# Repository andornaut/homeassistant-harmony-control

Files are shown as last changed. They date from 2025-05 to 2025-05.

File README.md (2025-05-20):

# homeassistant-harmony-remote

* [v1](./v1/)

Physical remote control for Home Assistant

Inspiration: [The Everything Remote](https://www.thestockpot.net/videos/theeverythingremote)

* [Overview (video)](https://www.youtube.com/watch?v=Pe_ozZkrRAw)
* [Build instructions (video)](https://www.youtube.com/watch?v=JU_7mb1ue7o&t=2059s)
* [3D models (.3mf and .step)](https://www.printables.com/model/1281626-everything-remote-esp32-powered-universal-remote)
* [Order PCB from PCBWay](https://www.pcbway.com/project/shareproject/The_Everything_Remote_The_Stock_Pot_ff1fe6b5.html)

## Bill of materials (BOM)

Item | Quantity | Description
--- | --- | ---
[Lithium Ion Battery - 1500mAh](https://www.sparkfun.com/lithium-ion-battery-1500mah-iec62133-certified.html) | 1 | 3.7V at 1500 mAh
[Mill-Max 315-43-116-41-001000](https://www.digikey.ca/en/products/detail/mill-max-manufacturing-corp/315-43-116-41-001000/4455239) | 2 | [315 series](https://mm.digikey.com/Volume0/opasdata/d220001/medias/docus/2481/310%2C%20311%2C%20315%20Series%20%28in.%29.pdf) "very low profile" 16-pin socket
[Mill-max 3320-0-00-15-00-00-03-0](https://www.digikey.ca/en/products/detail/mill-max-manufacturing-corp/3320-0-00-15-00-00-03-0/4147392) | 32 | Pins to connec the microcontroller to the sockets
[Panasonic ERJ-3EKF1002V](https://www.digikey.ca/en/products/detail/panasonic-electronic-components/ERJ-3EKF1002V/196066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) | 2 | 10 kΩ pull-up resistors
[SCHURTER tactile switches](https://www.digikey.ca/en/products/detail/schurter-inc/1301-9315-24/2643953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) | 24 | 6x6x0.5mm, 0.5A 12v
[SparkFun Thing Plus - ESP32 WROOM (USB-C)](https://www.sparkfun.com/sparkfun-thing-plus-esp32-wroom-usb-c.html) | 1 | Microcontroller

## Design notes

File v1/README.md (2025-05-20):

# Version 1 of the Homeassistant Harmony Remote

|col1 | col2 | col3|
|--- | --- | ---|
|Mute||Power|
|Vol↓||Vol↑|
||Up||
|Left|Select|Right|
||Down||
|Back||Home|

|col1| col2|
|--- | ---|
|Cameras|CBC|
|Crave|Netflix|
|Switch|VLC|
|Xbox|YouTube|

| GPIO Pin | Button ID | Wake Supported | External Pullup Resistor Required |
|---|---|:---:|:---:|
| GPIO4 | power | Yes | |
| GPIO12 | home | Yes | |
| GPIO13 | mute | Yes | |
| GPIO14 | shortcut_1 | Yes | |
| GPIO16 | shortcut_2 | | |
| GPIO17 | shortcut_3 | | |
| GPIO18 | shortcut_4 | | |
| GPIO19 | shortcut_5 | | |
| GPIO21 | shortcut_6 | | |
| GPIO22 | shortcut_7 | | |
| GPIO23 | shortcut_8 | | |
| GPIO25 | volume_up | Yes | |
| GPIO26 | volume_down | Yes | |
| GPIO27 | select_button | Yes | |
| GPIO32 | back | Yes | |
| GPIO33 | left | Yes | |
| GPIO34 | right | Yes | Yes |
| GPIO36 | up | Yes | Yes |
| GPIO39 | down | Yes | Yes |

## Software

* [Setting up ESPHome for Home Assistant (video)](https://www.youtube.com/watch?v=7PoUWszwaFk)

1. Navigate to [https://web.esphome.io/](https://web.esphome.io/) using Google Chrome
1. Connect the remote via USB
1. Click "Connect" and select the remote device
1. Click "Prepare for first use"
   * Press and hold the "Boot" button on the microcontroller to enter programming mode
1. Click "Connect to wi-fi"
1. Navigate to [ESPHome Device Builder](https://esphome.io/guides/getting_started_command_line#esphome-device-builder-docker)

Run Google Chrome as root to avoid permission problems when attempting to access the USB port:

```bash
sudo google-chrome --no-sandbox --no-first-run --no-default-browser-check &
```

## Hardware

### Bill of materials (BOM)

Category | Quantity | Part
--- | --- | ---
Microcontroller | 1 | [SparkFun Thing Plus - ESP32 WROOM (USB-C)](https://www.sparkfun.com/sparkfun-thing-plus-esp32-wroom-usb-c.html) ([pin out](https://cdn.sparkfun.com/assets/3/9/5/f/e/SparkFun_Thing_Plus_ESP32_WROOM_C_graphical_datasheet2.pdf))
Screws | 4 | M3x8mm screws
Sockets (16-pin)| 2 | [Mill-Max 315-43-116-41-001000](https://www.digikey.ca/en/products/detail/mill-max-manufacturing-corp/315-43-116-41-001000/4455239)
Socket pins | 32 | [Mill-Max 3320-0-00-15-00-00-03-0](https://www.digikey.ca/en/products/detail/mill-max-manufacturing-corp/3320-0-00-15-00-00-03-0/4147392)
Threaded inserts | 4 | [M3x3mm (short) threaded inserts](https://cnckitchen.store/products/gewindeeinsatz-threaded-insert-m3-short-100-stk-pcs)

### Set ESP32 flash voltage to 3.3v to use GPIO12 for a button

* [esptool GitHub](https://github.com/espressif/esptool)
* [espefuse.py documentation](https://docs.espressif.com/projects/esptool/en/latest/esp32/espefuse/index.html)

In order to use GPIO12 for a button, we must ensure the ESP32 always uses 3.3V for flash voltage.

**Warning:** This is permanent! Only do this if you are sure your board uses 3.3V flash like the SparkFun ESP32 Thing Plus.

```bash
sudo apt install python3 python3-pip
python3 -m venv .venv
source .venv/bin/activate
pip3 install esptool

# Plug in your SparkFun ESP32 Thing Plus (USB-C) and find your its serial port
ls /dev/ttyUSB* /dev/ttyACM* 2>/dev/null

# Read the initial state
espefuse.py --port /dev/ttyUSB1 summary

# Set the flash voltage to 3.3V
espefuse.py --port /dev/ttyUSB1 set_flash_voltage 3.3V

# Verify the new state: look for a line like:
# VDD_SDIO: 3.3V (set by eFuse)
espefuse.py --port /dev/ttyUSB1 summary
```

## Developing

* [Overall process](../README.md#developing)

### [Ergogen](https://github.com/ergogen/ergogen)

* [Project folder](./ergogen)
* [Configuration file](./ergogen/config.yaml)

Ergogen preview

1. Convert the prototype to Ergogen's DSL, and then save it to [`./ergogen/config.yaml`](./ergogen/config.yaml)
   * If prototyping using this [online version of Ergogen](https://ergogen.cache.works/), then download the "raw.txt" file
1. Run `npm run build` to generate and save outlines and pcbs to `../dist/v1/ergogen/`
    * Alternatively, run `npm run watch` or `npm run watch-and-copy-pcbs-to-kicad`

### [KiCad](https://www.kicad.org/)

* [Project folder](./kicad)

KiCad preview

1. Run `npm run copy-pcbs-to-kicad` to copy the `../dist/v1/ergogen/pcbs/*.kicad_pcb` files generated by Ergogen to [`./kicad/`](./kicad/)
1. Run `xdg-open ./v2/kicad/left.kicad_pcb`
1. Route the PCBs in [`./kicad/`](./kicad/), and then save them to [`./kicad/routed/`](./kicad/routed/)
    * If you've generated new PCB files using Ergogen, then you can run `npm run copy-traces-from-routed` to copy traces from the PCBs in [`./kicad/routed/`](./kicad/routed/) back to those of the same name in [`./kicad/`](./kicad/)
1. Run `npm run copy-pcbs-to-routed && npm run fab-jlcpcb` to generate and save gerber and drill files to `../dist/v1/kicad/jlcpcb/*.zip`
1. Submit the `../dist/v1/kicad/jlcpcb/*.zip` files to [JLCPCB](https://jlcpcb.com/)

### [OnShape](https://cad.onshape.com)

* [Project folder](./onshape)

OnShape preview

1. Create a new document
1. Start a new sketch
1. Select "Import DXF or DWG files" > "Import ..." (at the bottom of the dialog) > Select `../dist/v2/ergogen/outlines/full.dxf`
1. Design a keyboard case
1. Export `*.step` files to [`./onshape/`](./onshape/)

### [OrcaSlicer](https://github.com/SoftFever/OrcaSlicer)

1. Open or create an OrcaSlicer project file
1. Import `*.step` files from [`./onshape/`](./onshape/)
1. Print the keyboard case

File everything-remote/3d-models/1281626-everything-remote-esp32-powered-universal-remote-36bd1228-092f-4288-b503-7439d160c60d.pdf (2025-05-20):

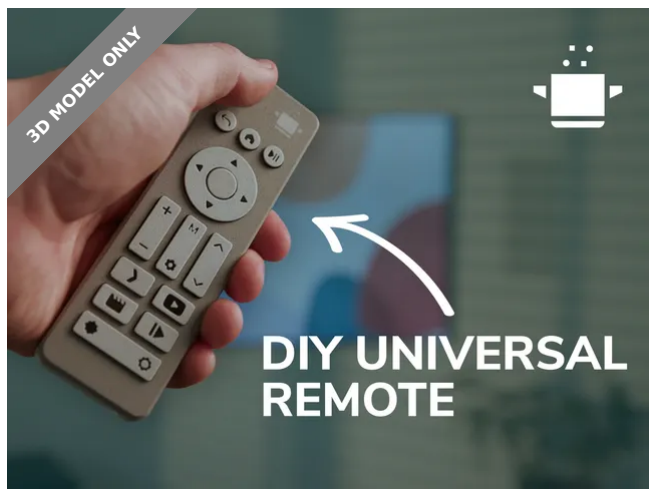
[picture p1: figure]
3D MODEL ONLY

## Summary

ESPHome-powered universal remote for Home Assistant. 3D printable case, labeled/blank buttons + full guide.

Gadgets (https://printables.com/model?categoryId=21) > Portable Devices (https://printables.com/model?categoryId=28)

Tags: | esp32 | smarthome | thestockpot

UPDATED 8/5 - Replaced Shell_Bottom and Shell_Top with fixed versions

Build your own universal smart remote!

This project turns a simple ESP32 and tactile buttons into a powerful, battery-powered remote for Home Assistant — perfect for media control, lights, scenes and more.

You can 3D print this enclosure, solder up the simple electronics, and load my ESPHome config to get started right away. No coding skills required! Check out the resources below for everything you need to make your own:

Blog Post (https://www.thestockpot.net/videos/theeverythingremote)
Purchase PCB (https://www.pcbway.com/project/shareproject/The_Everything_Remote_The_Stock_Pot_ff1fe6b5.html)

The Stock Pot (https://printables.com/@TheStockPot_2973732)

## Everything Remote - ESP32 Powered Universal Remote

VIEW IN BROWSER (https://printables.com/model/1281626-everything-remote-esp32-powered-universal-remote)

updated 7. 5. 2025 | published 7. 5. 2025

•
•

## Model files

Tutorial Video
Files:

Buttons_Icons

Pre-labeled buttons for media controls, shortcuts, volume, channel and lighting. Ready to print.

Buttons_Blank

No icons — perfect for adding your own labels or custom SVG icons in your slicer.

Shell_Botton & Shell_Top

The same shell is used for both button versions

STEP file

The enclosure and PCB in STEP format so you can make your own version of the everything remote

Recommended Print Settings:

PLA or PETG
0.2mm nozzle for the buttons
0.12–0.16mm layer height for best icon detail
Buttons: Print face down for clean top finish
Enclosure: Supports recommended (especially for screw bosses) Supports filament color changes for button icons (optional but looks fantastic!).
- Updated to fix seperated clips
- Updated to fix missing clip slots

•
•
•
•
•
•

shell_top.3mf

shell_bottom.3mf

- No icons - for adding icons in slicer
- Includes icons featured in video

## License

This work is licensed under a
Creative Commons (4.0 International License)

Attribution (http://creativecommons.org/licenses/by/4.0/)

✖ | Sharing without ATTRIBUTION
✔ | Remix Culture allowed
✔ | Commercial Use
✔ | Free Cultural Works
✔ | Meets Open Definition

buttons_blank.3mf

buttons_icons.3mf

blank_shell.step

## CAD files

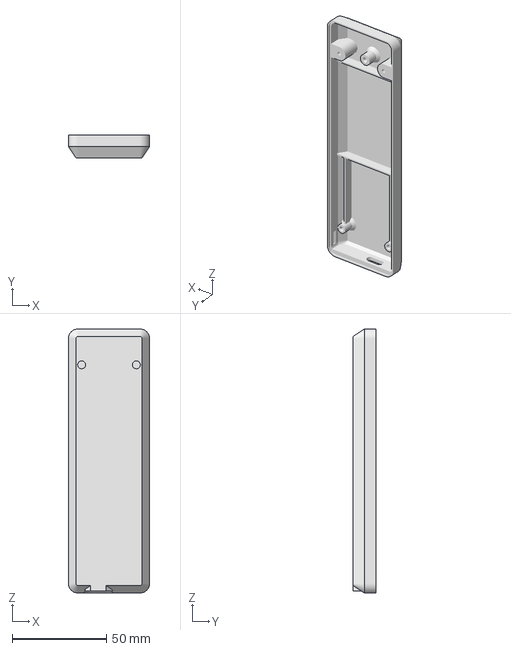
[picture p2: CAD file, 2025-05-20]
everything-remote/3d-models/shell_bottom.3mf
43.0 x 12.3 x 140.0 mm

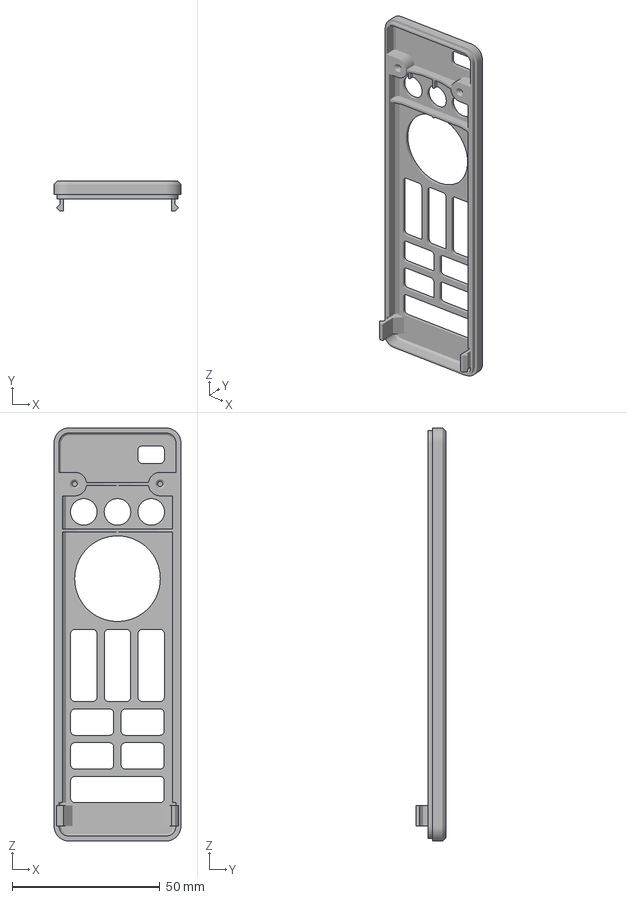
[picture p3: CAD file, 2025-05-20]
everything-remote/3d-models/shell_top.3mf
43.0 x 10.3 x 140.0 mm

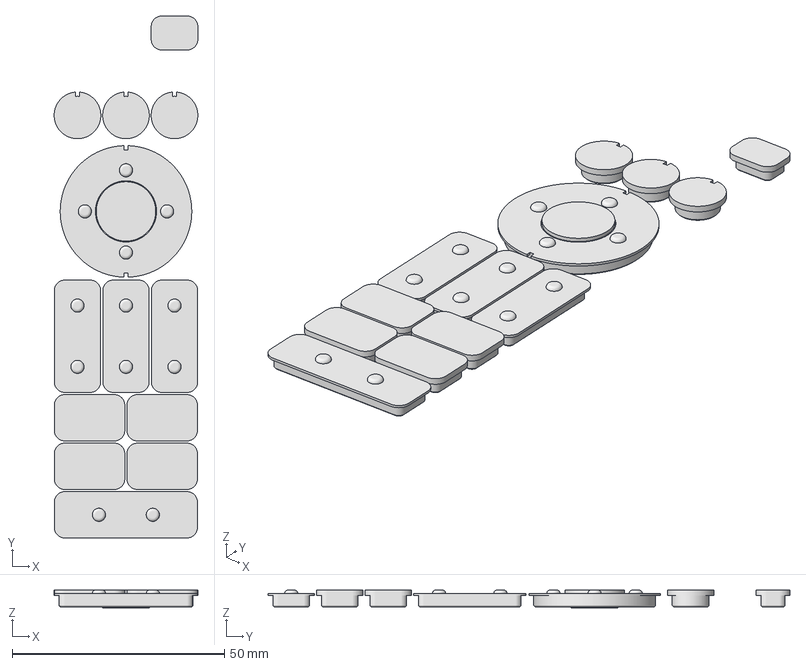
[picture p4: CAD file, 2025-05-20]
everything-remote/3d-models/buttons_icons.3mf
33.9 x 123.0 x 4.20 mm
Back
Channel
Directional
Home
Mute / Settings
Play
Power
Select
Shortcut 1
Shortcut 2
Shortcut 3
Shortcut 4
Shortcut 5
Volume

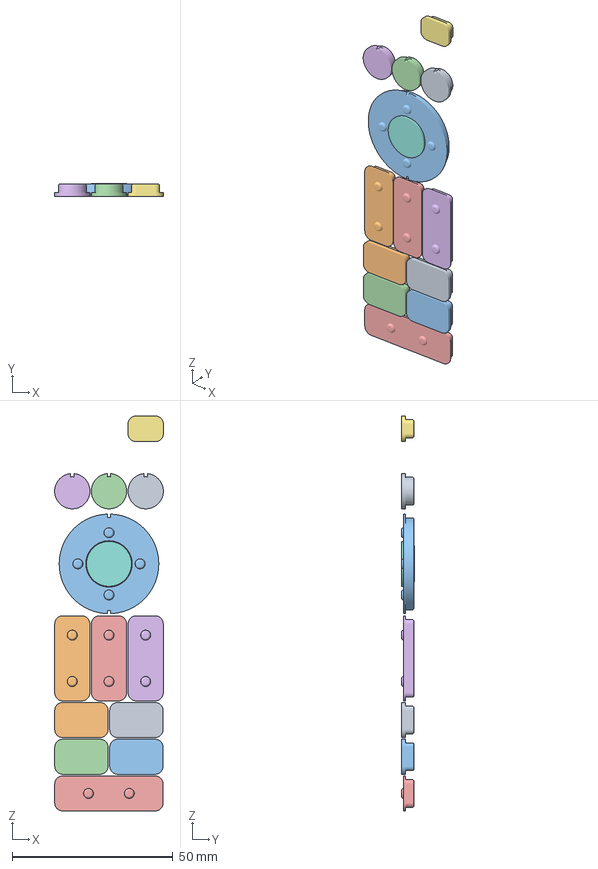
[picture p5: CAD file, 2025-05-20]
everything-remote/3d-models/buttons_blank.3mf
33.9 x 4.20 x 123.0 mm
Back
Channel
Directional
Home
Mute / Settings
Play
Power
Select
Shortcut 1
Shortcut 2
Shortcut 3
Shortcut 4
Shortcut 5
Volume
